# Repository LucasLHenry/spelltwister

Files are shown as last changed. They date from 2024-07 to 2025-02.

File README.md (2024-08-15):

# spelltwister
Spelltwister is a dual function generator with a large palette of modulation algorithms. It has three modes: ENV (slow, single-cycle), LFO (slow, free-running), and VCO (fast, free-running). Each side of the module is a waveformer, which generates a signal controlled by three knobs. The basic structure of this signal is that of an AD envelope, so the signal first rises to it's maximum value (in a variable time and curvature), then falls back to it's minimum value (in a variable time and curvature). 

The three knobs are Time, Shape, and Ratio. Time controls the overall time for one cycle of the waveform, so also functions as pitch in VCO mode. Ratio controls the ratio between the time spent on the first stage versus the second stage (so ratio set fully CCW would mean that all time is spent falling, which would form a downwards saw wave). Lastly, Shape controls the curvature of the rising and falling, from exponential to logarithmic. With Shape in it's center position, the slope is linear, but turning it below 12 o'clock makes the rising and falling more exponential, while turning it the other way makes it more logarithmic.

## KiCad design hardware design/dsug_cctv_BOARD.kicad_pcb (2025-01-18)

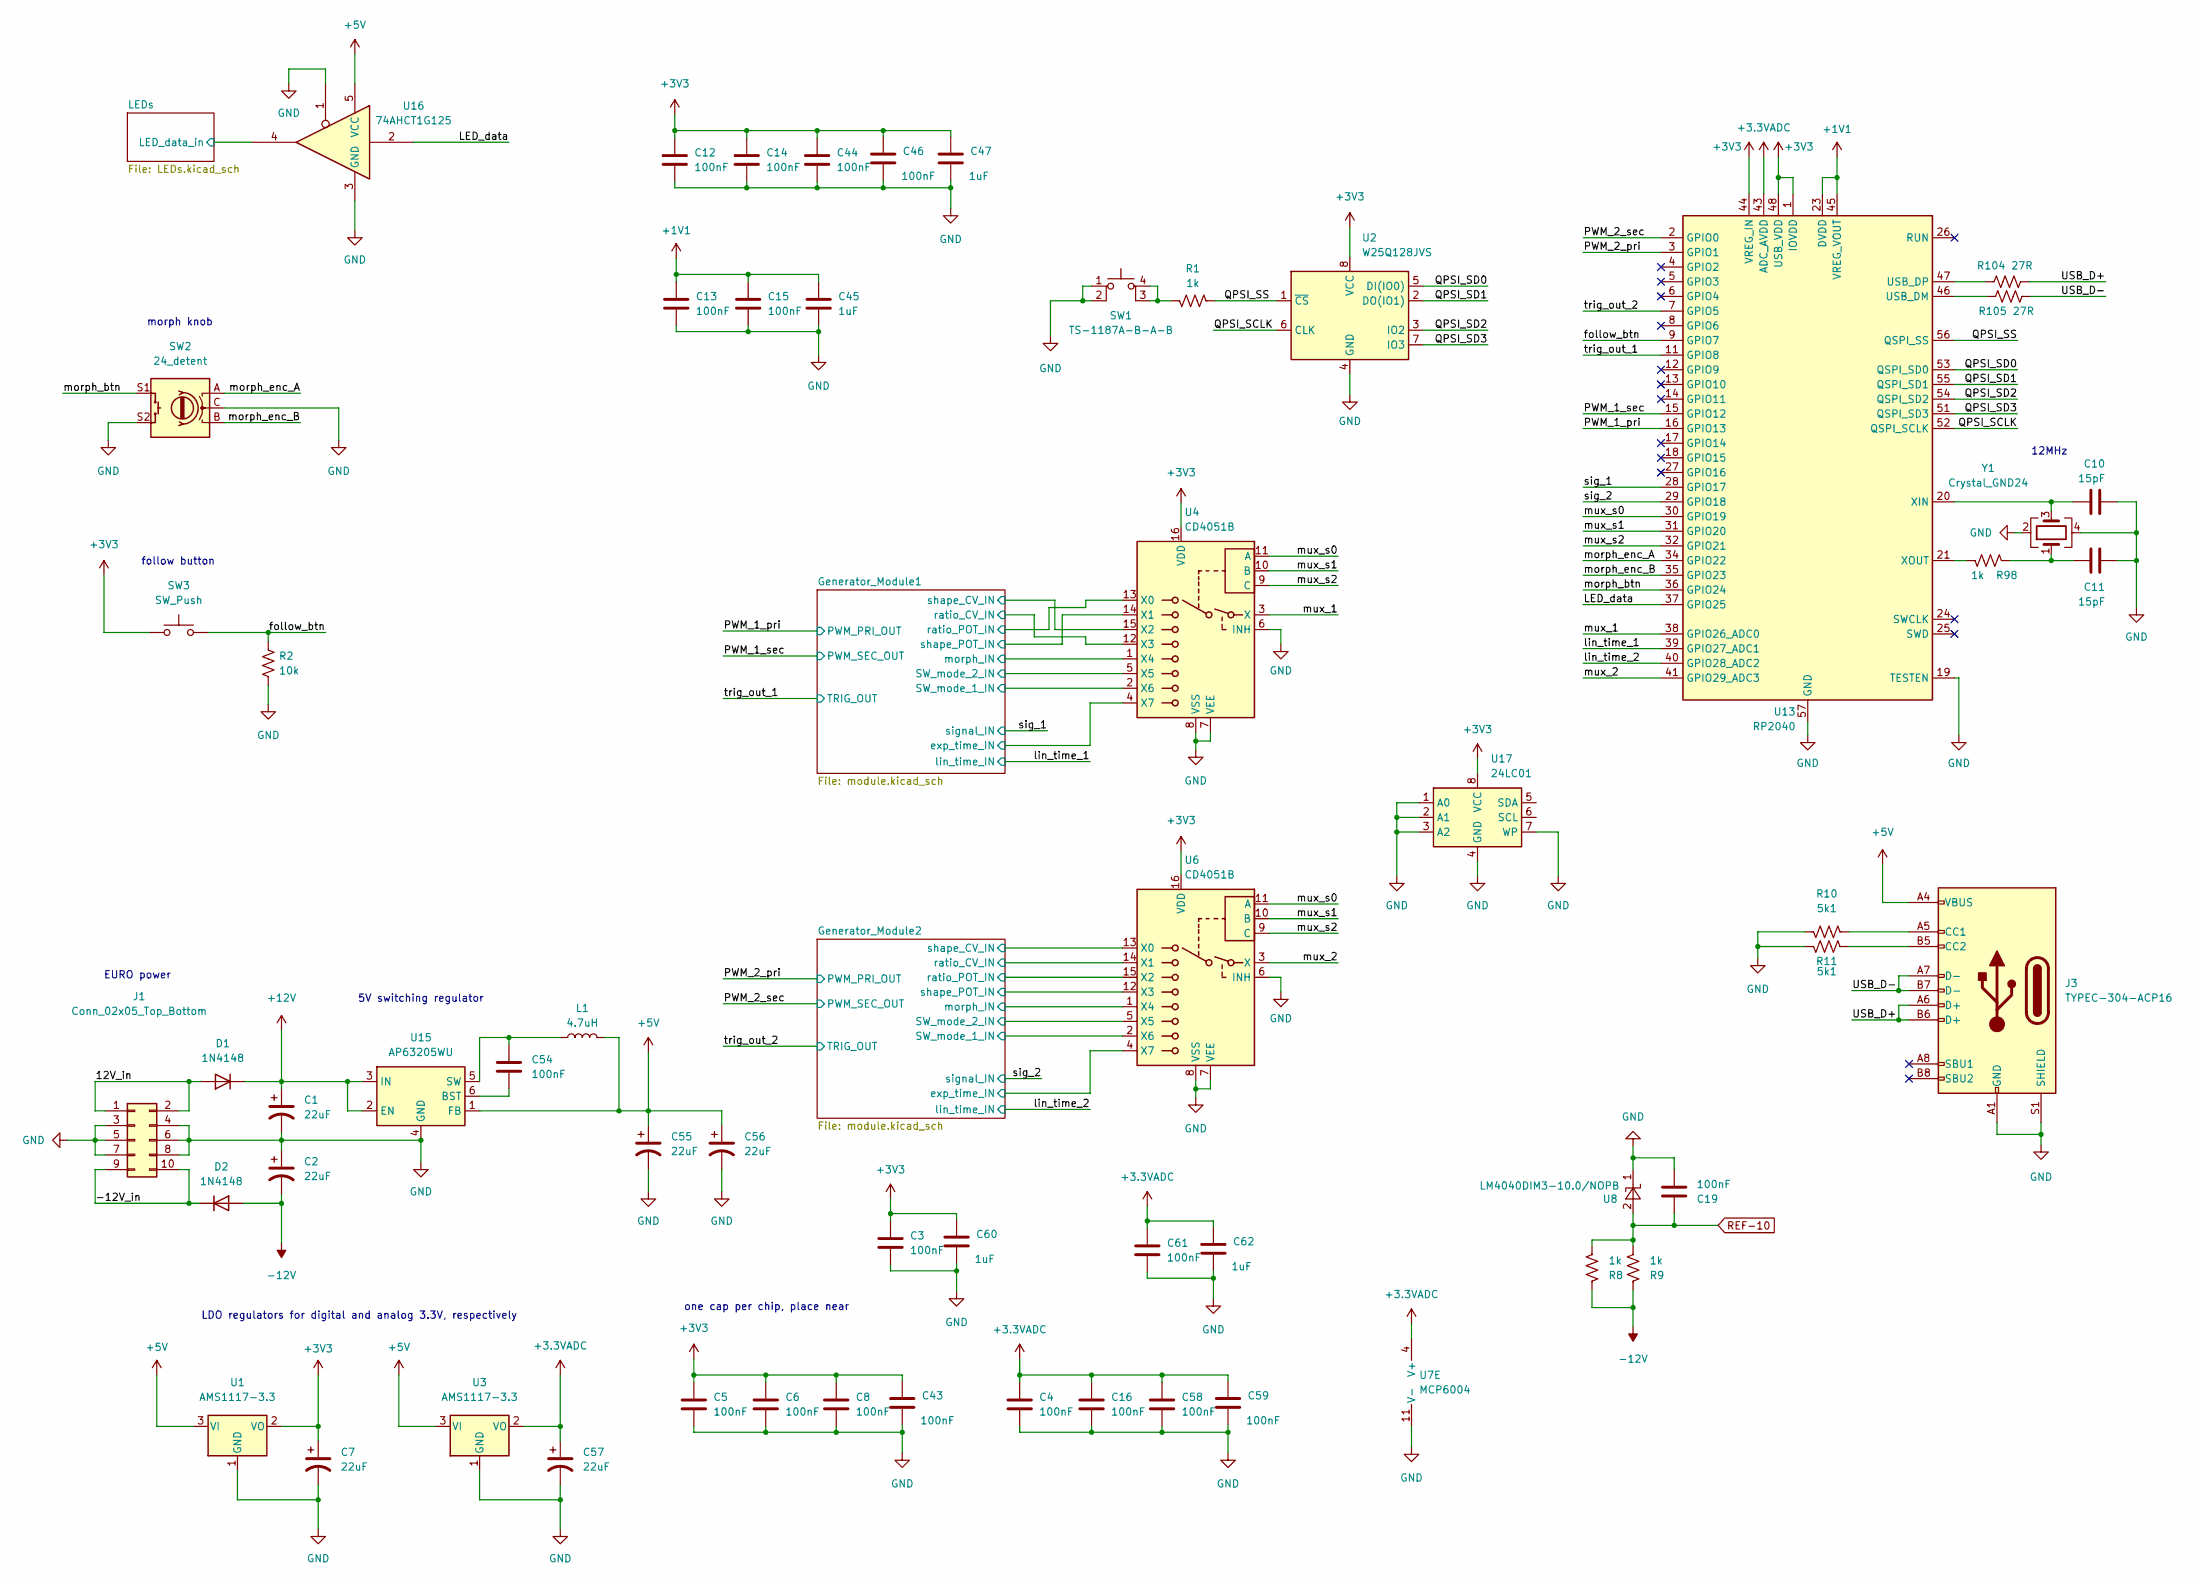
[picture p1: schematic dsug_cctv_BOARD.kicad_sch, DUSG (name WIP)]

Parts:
C1, C2, C7, C55, C56, C57: 22uF; CP_Radial_D5.0mm_P2.50mm
C3, C4, C5, C6, C8, C12, C13, C14, C15, C16, C19, C43, C44, C46, C54, C58, C59, C61: 100nF; C_0603_1608Metric
C10, C11: 15pF; C_0603_1608Metric
C45, C47, C60, C62: 1uF; C_0603_1608Metric
D1, D2: 1N4148; D_SOD-123
J1: Conn_02x05_Top_Bottom; PinHeader_2x05_P2.54mm_Vertical
J3: TYPEC-304-ACP16; USB_C_Receptacle_HRO_TYPE-C-31-M-12
L1: 4.7uH; L_TaiTech_HPC3010TF-4R7M
R1, R8, R9, R98: 1k; R_0603_1608Metric
R2: 10k; R_0603_1608Metric
R10, R11: 5k1; R_0603_1608Metric
R104, R105: 27R; R_0603_1608Metric
SW1: TS-1187A-B-A-B; push_switch_5.1x5.1
SW2: 24_detent; RotaryEncoder_Switch_Vertical_H20mm_20mm_knob
SW3: SW_Push; SW_PUSH_6mm
U1, U3: AMS1117-3.3; SOT-223-3_TabPin2
U2: W25Q128JVS; SOIC-8_5.23x5.23mm_P1.27mm
U4, U6: CD4051B; SOIC-16_3.9x9.9mm_P1.27mm
U7: MCP6004; SOIC-14_3.9x8.7mm_P1.27mm
U8: LM4040DIM3-10.0/NOPB; SOT-23
U13: RP2040; QFN-56-1EP_7x7mm_P0.4mm_EP3.2x3.2mm
U15: AP63205WU; TSOT-23-6
U16: 74AHCT1G125; SOT-353_SC-70-5
U17: 24LC01
Y1: Crystal_GND24; ABM8-272-T3_ABR

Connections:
+1V1: C13.1, C15.1, C45.1, U13.23 (DVDD), U13.45 (VREG_VOUT), U13.50 (DVDD)
+3.3VADC: C4.1, C16.1, C57.1, C58.1, C59.1, C61.1, C62.1, U3.2 (VO), U7.4 (V+), U13.43 (ADC_AVDD); also elsewhere on the board
+3V3: C3.1, C5.1, C6.1, C7.1, C8.1, C12.1, C14.1, C43.1, C44.1, C46.1, C47.1, C60.1, SW3.1, U1.2 (VO), U2.8 (VCC), U4.16 (VDD), U6.16 (VDD), U13.1 (IOVDD), U13.10 (IOVDD), U13.22 (IOVDD), U13.33 (IOVDD), U13.42 (IOVDD), U13.44 (VREG_IN), U13.48 (USB_VDD), U13.49 (IOVDD), U17.8 (VCC); also elsewhere on the board
+5V: C55.1, C56.1, J3.A4 (VBUS), J3.A9 (VBUS), J3.B4 (VBUS), J3.B9 (VBUS), L1.2, U1.3 (VI), U3.3 (VI), U15.1 (FB), U16.5 (VCC); also elsewhere on the board
+12V: C1.1, D1.1 (K), U15.2 (EN), U15.3 (IN); also elsewhere on the board
-12V: C2.2, D2.2 (A), R8.1, R9.1; also elsewhere on the board
/12V_in: D1.2 (A), J1.1, J1.2
/-12V_in: D2.1 (K), J1.9, J1.10
/Generator_Module1/SW_mode_1_IN: U4.2 (X6); also elsewhere on the board
/Generator_Module1/SW_mode_2_IN: U4.5 (X5); also elsewhere on the board
/Generator_Module1/exp_time_IN: U4.4 (X7); also elsewhere on the board
/Generator_Module1/morph_IN: U4.1 (X4); also elsewhere on the board
/Generator_Module1/ratio_CV_IN: U4.12 (X3); also elsewhere on the board
/Generator_Module1/ratio_pot: U4.13 (X0); also elsewhere on the board
/Generator_Module1/shape_CV_IN: U4.15 (X2); also elsewhere on the board
/Generator_Module1/shape_pot: U4.14 (X1); also elsewhere on the board
/Generator_Module2/SW_mode_1_IN: U6.2 (X6); also elsewhere on the board
/Generator_Module2/SW_mode_2_IN: U6.5 (X5); also elsewhere on the board
/Generator_Module2/exp_time_IN: U6.4 (X7); also elsewhere on the board
/Generator_Module2/morph_IN: U6.1 (X4), U7.14; also elsewhere on the board
/Generator_Module2/ratio_CV_IN: U6.14 (X1); also elsewhere on the board
/Generator_Module2/ratio_pot: U6.15 (X2); also elsewhere on the board
/Generator_Module2/shape_CV_IN: U6.13 (X0); also elsewhere on the board
/Generator_Module2/shape_pot: U6.12 (X3); also elsewhere on the board
/LED_data: U13.37 (GPIO25), U16.2
/LEDs/LED_data_in: U16.4; also elsewhere on the board
/PWM_1_pri: U13.16 (GPIO13); also elsewhere on the board
/PWM_1_sec: U13.15 (GPIO12); also elsewhere on the board
/PWM_2_pri: U13.3 (GPIO1); also elsewhere on the board
/PWM_2_sec: U13.2 (GPIO0); also elsewhere on the board
/QPSI_SCLK: U2.6 (CLK), U13.52 (QSPI_SCLK)
/QPSI_SD0: U2.5 (DI(IO0)), U13.53 (QSPI_SD0)
/QPSI_SD1: U2.2 (DO(IO1)), U13.55 (QSPI_SD1)
/QPSI_SD2: U2.3 (IO2), U13.54 (QSPI_SD2)
/QPSI_SD3: U2.7 (IO3), U13.51 (QSPI_SD3)
/QPSI_SS: R1.2, U2.1 (~CS), U13.56 (QSPI_SS)
/USB_D+: J3.A6 (D+), J3.B6 (D+), R104.2
/USB_D-: J3.A7 (D-), J3.B7 (D-), R105.2
/follow_btn: R2.1, SW3.2, U13.9 (GPIO7)
/lin_time_1: U13.39 (GPIO27_ADC1); also elsewhere on the board
/lin_time_2: U13.40 (GPIO28_ADC2); also elsewhere on the board
/morph_btn: SW2.S1, U13.36 (GPIO24)
/morph_enc_A: SW2.A, U13.34 (GPIO22)
/morph_enc_B: SW2.B, U13.35 (GPIO23)
/mux_1: U4.3 (X), U13.38 (GPIO26_ADC0)
/mux_2: U6.3 (X), U13.41 (GPIO29_ADC3)
/mux_s0: U4.11 (A), U6.11 (A), U13.30 (GPIO19)
/mux_s1: U4.10 (B), U6.10 (B), U13.31 (GPIO20)
/mux_s2: U4.9 (C), U6.9 (C), U13.32 (GPIO21)
/sig_1: U13.28 (GPIO17); also elsewhere on the board
/sig_2: U7.8, U13.29 (GPIO18); also elsewhere on the board
/trig_out_1: U13.11 (GPIO8); also elsewhere on the board
/trig_out_2: U13.7 (GPIO5); also elsewhere on the board
GND: C1.2, C2.1, C3.2, C4.2, C5.2, C6.2, C7.2, C8.2, C10.2, C11.2, C12.2, C13.2, C14.2, C15.2, C16.2, C19.2, C43.2, C44.2, C45.2, C46.2, C47.2, C55.2, C56.2, C57.2, C58.2, C59.2, C60.2, C61.2, C62.2, J1.3, J1.4, J1.5, J1.6, J1.7, J1.8, J3.A1 (GND), J3.A12 (GND), J3.B1 (GND), J3.B12 (GND), J3.S1 (SHIELD), R2.2, R10.2, R11.2, SW1.1, SW1.2, SW2.C, SW2.S2, U1.1 (GND), U2.4 (GND), U3.1 (GND), U4.6 (INH), U4.7 (VEE), U4.8 (VSS), U6.6 (INH), U6.7 (VEE), U6.8 (VSS), U7.10 (+), U7.11 (V-), U7.12 (+), U8.1 (K), U13.19 (TESTEN), U13.57 (GND), U15.4 (GND), U16.1, U16.3 (GND), U17.1 (A0), U17.2 (A1), U17.3 (A2), U17.4 (GND), U17.7 (WP), Y1.2, Y1.4; also elsewhere on the board
unnamed: C11.1, R98.1, Y1.1
unnamed: J3.A5 (CC1), R10.1
unnamed: J3.B5 (CC2), R11.1
unnamed: R1.1, SW1.3 (K), SW1.4 (A)
unnamed 140: U7.9 (-); also elsewhere on the board
unnamed 141: U7.13 (-); also elsewhere on the board
unnamed: R105.1, U13.46 (USB_DM)
unnamed: R104.1, U13.47 (USB_DP)
unnamed: C10.1, U13.20 (XIN), Y1.3
unnamed: R98.2, U13.21 (XOUT)
unnamed: C54.2, U15.6 (BST)
unnamed: C54.1, L1.1, U15.5 (SW)
REF-10: C19.1, R8.2, R9.2, U8.2 (A); also elsewhere on the board

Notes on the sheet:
one cap per chip, place near
5V switching regulator
LDO regulators for digital and analog 3.3V, respectively
EURO power
morph knob
12MHz
follow button

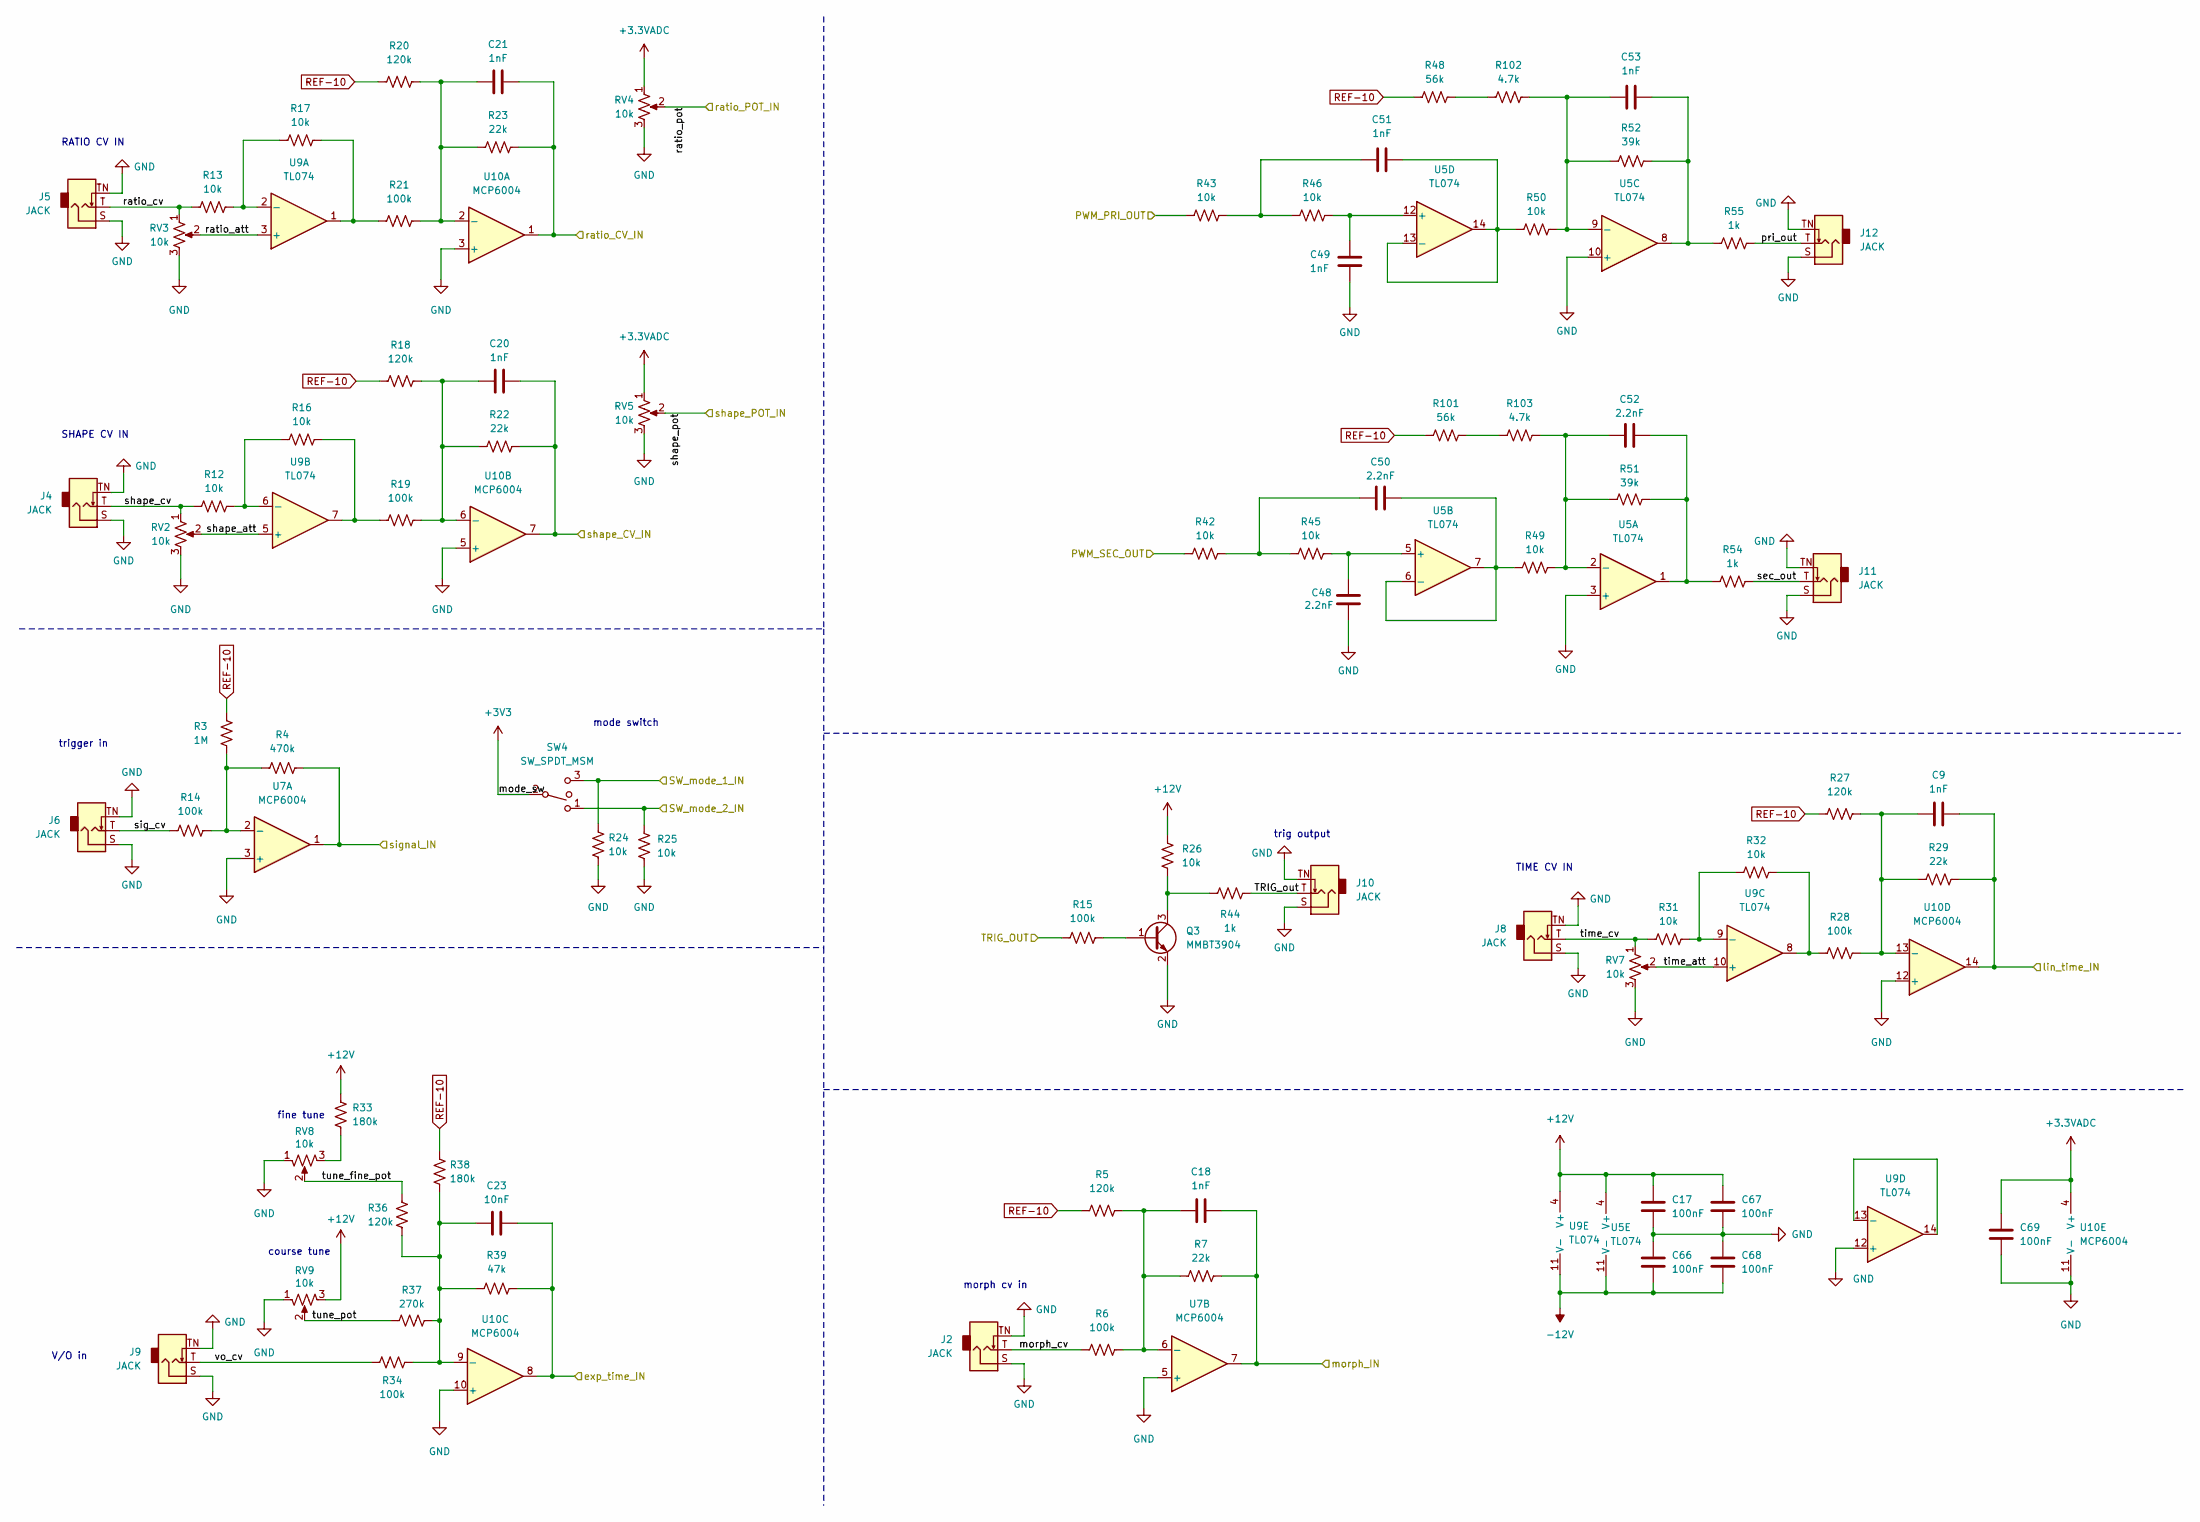
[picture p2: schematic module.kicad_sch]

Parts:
C9, C18, C20, C21, C49, C51, C53: 1nF; C_0603_1608Metric
C17, C66, C67, C68, C69: 100nF; C_0603_1608Metric
C23: 10nF; C_0603_1608Metric
C48, C50, C52: 2.2nF; C_0603_1608Metric
J2, J4, J5, J6, J8, J9, J10, J11, J12: JACK; AudioJack_3.5mm_with_drawing
Q3: MMBT3904; SOT-23
R3: 1M; R_0603_1608Metric
R4: 470k; R_0603_1608Metric
R5, R18, R20, R27, R36: 120k; R_0603_1608Metric
R6, R14, R15, R19, R21, R28, R34: 100k; R_0603_1608Metric
R7, R22, R23, R29: 22k; R_0603_1608Metric
R12, R13, R16, R17, R24, R25, R26, R31, R32, R42, R43, R45, R46, R49, R50: 10k; R_0603_1608Metric
R33, R38: 180k; R_0603_1608Metric
R37: 270k; R_0603_1608Metric
R39: 47k; R_0603_1608Metric
R44, R54, R55: 1k; R_0603_1608Metric
R48, R101: 56k; R_0603_1608Metric
R51, R52: 39k; R_0603_1608Metric
R102, R103: 4.7k; R_0603_1608Metric
RV2, RV3, RV7, RV8: 10k; Potentiometer_RV09_talltrimmer
RV4, RV5, RV9: 10k; Potentiometer_RV09_6mm_knob
SW4: SW_SPDT_MSM; SPDT_P2.54mm_Vertical
U5, U9: TL074; SOIC-14_3.9x8.7mm_P1.27mm
U7, U10: MCP6004; SOIC-14_3.9x8.7mm_P1.27mm

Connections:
+3.3VADC: C69.1, RV4.1, RV5.1, U10.4 (V+); also elsewhere on the board
+3V3: SW4.2; also elsewhere on the board
+12V: C17.1, C67.1, R26.1, R33.1, RV9.3, U5.4 (V+), U9.4 (V+); also elsewhere on the board
-12V: C66.2, C68.2, U5.11 (V-), U9.11 (V-); also elsewhere on the board
/Generator_Module1/SW_mode_1_IN: R24.1, SW4.3; also elsewhere on the board
/Generator_Module1/SW_mode_2_IN: R25.1, SW4.1; also elsewhere on the board
/Generator_Module1/TRIG_out: J10.T, R44.1
/Generator_Module1/exp_time_IN: C23.2, R39.2, U10.8; also elsewhere on the board
/Generator_Module1/morph_IN: C18.2, R7.2, U7.7; also elsewhere on the board
/Generator_Module1/morph_cv: J2.T, R6.1
/Generator_Module1/pri_out: J12.T, R55.2
/Generator_Module1/ratio_CV_IN: C21.2, R23.2, U10.1; also elsewhere on the board
/Generator_Module1/ratio_att: RV3.2, U9.3 (+)
/Generator_Module1/ratio_cv: J5.T, R13.1, RV3.1
/Generator_Module1/ratio_pot: RV4.2; also elsewhere on the board
/Generator_Module1/sec_out: J11.T, R54.2
/Generator_Module1/shape_CV_IN: C20.2, R22.2, U10.7; also elsewhere on the board
/Generator_Module1/shape_att: RV2.2, U9.5 (+)
/Generator_Module1/shape_cv: J4.T, R12.1, RV2.1
/Generator_Module1/shape_pot: RV5.2; also elsewhere on the board
/Generator_Module1/sig_cv: J6.T, R14.1
/Generator_Module1/time_att: RV7.2, U9.10 (+)
/Generator_Module1/time_cv: J8.T, R31.1, RV7.1
/Generator_Module1/tune_fine_pot: R36.1, RV8.2
/Generator_Module1/tune_pot: R37.1, RV9.2
/Generator_Module1/vo_cv: J9.T, R34.1
/Generator_Module2/morph_IN: U7.14; also elsewhere on the board
/PWM_1_pri: R43.1; also elsewhere on the board
/PWM_1_sec: R42.1; also elsewhere on the board
/lin_time_1: C9.2, R29.2, U10.14; also elsewhere on the board
/sig_1: R4.2, U7.1; also elsewhere on the board
/sig_2: U7.8; also elsewhere on the board
/trig_out_1: R15.1; also elsewhere on the board
GND: C17.2, C48.1, C49.2, C66.1, C67.2, C68.1, C69.2, J2.S, J2.TN, J4.S, J4.TN, J5.S, J5.TN, J6.S, J6.TN, J8.S, J8.TN, J9.S, J9.TN, J10.S, J10.TN, J11.S, J11.TN, J12.S, J12.TN, Q3.2 (E), R24.2, R25.2, RV2.3, RV3.3, RV4.3, RV5.3, RV7.3, RV8.1, RV9.1, U5.3 (+), U5.10 (+), U7.3 (+), U7.5 (+), U7.10 (+), U7.12 (+), U9.12 (+), U10.3 (+), U10.5 (+), U10.10 (+), U10.11 (V-), U10.12 (+); also elsewhere on the board
unnamed: C50.1, R42.2, R45.1
unnamed: C51.1, R43.2, R46.1
unnamed: C52.2, R51.2, R54.1, U5.1
unnamed: C53.2, R52.2, R55.1, U5.8
unnamed: Q3.1 (B), R15.2
unnamed: Q3.3 (C), R26.2, R44.2
unnamed: R16.2, R19.1, U9.7
unnamed: R17.2, R21.1, U9.1
unnamed: R28.1, R32.2, U9.8
unnamed: R33.2, RV8.3
unnamed: R101.2, R103.1
unnamed: R48.2, R102.1
unnamed: C52.1, R49.2, R51.1, R103.2, U5.2 (-)
unnamed: C48.2, R45.2, U5.5 (+)
unnamed: C50.2, R49.1, U5.6 (-), U5.7
unnamed: C53.1, R50.2, R52.1, R102.2, U5.9 (-)
unnamed: C49.1, R46.2, U5.12 (+)
unnamed: C51.2, R50.1, U5.13 (-), U5.14
unnamed: R3.1, R4.1, R14.2, U7.2 (-)
unnamed: C18.1, R5.2, R6.2, R7.1, U7.6 (-)
unnamed 140: U7.9 (-); also elsewhere on the board
unnamed 141: U7.13 (-); also elsewhere on the board
unnamed: R13.2, R17.1, U9.2 (-)
unnamed: R12.2, R16.1, U9.6 (-)
unnamed: R31.2, R32.1, U9.9 (-)
unnamed: U9.13 (-), U9.14
unnamed: C21.1, R20.2, R21.2, R23.1, U10.2 (-)
unnamed: C20.1, R18.2, R19.2, R22.1, U10.6 (-)
unnamed: C23.1, R34.2, R36.2, R37.2, R38.1, R39.1, U10.9 (-)
unnamed: C9.1, R27.2, R28.2, R29.1, U10.13 (-)
REF-10: R3.2, R5.1, R18.1, R20.1, R27.1, R38.2, R48.1, R101.1; also elsewhere on the board

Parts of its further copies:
C22: 10nF; C_0603_1608Metric
C28, C29, C30, C32, C34, C36, C41: 1nF; C_0603_1608Metric
C31, C33, C35: 2.2nF; C_0603_1608Metric
C37, C38, C39, C40, C42: 100nF; C_0603_1608Metric
J7, J13, J14, J15, J16, J17, J18, J19, J20: JACK; AudioJack_3.5mm_with_drawing
Q4: MMBT3904; SOT-23
R30: 1M; R_0603_1608Metric
R35, R59, R61, R63, R72, R74, R96: 100k; R_0603_1608Metric
R40, R41, R56, R57, R70, R71, R75, R77, R78, R80, R81, R86, R87, R91, R94: 10k; R_0603_1608Metric
R53: 470k; R_0603_1608Metric
R58, R66: 180k; R_0603_1608Metric
R60, R62, R64, R73, R95: 120k; R_0603_1608Metric
R65: 270k; R_0603_1608Metric
R67: 47k; R_0603_1608Metric
R68, R69, R76, R97: 22k; R_0603_1608Metric
R79, R92, R93: 1k; R_0603_1608Metric
R82, R83: 56k; R_0603_1608Metric
R84, R85: 4.7k; R_0603_1608Metric
R89, R90: 39k; R_0603_1608Metric
RV1, RV6, RV10, RV14: 10k; Potentiometer_RV09_talltrimmer
RV11, RV12, RV13: 10k; Potentiometer_RV09_6mm_knob
SW5: SW_SPDT_MSM; SPDT_P2.54mm_Vertical
U11: MCP6004; SOIC-14_3.9x8.7mm_P1.27mm
U12, U14: TL074; SOIC-14_3.9x8.7mm_P1.27mm

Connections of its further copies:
+3.3VADC: C42.1, RV12.1, RV13.1, U11.4 (V+); also elsewhere on the board
+3V3: SW5.2; also elsewhere on the board
+12V: C37.1, C39.1, R58.1, R75.1, RV11.3, U12.4 (V+), U14.4 (V+); also elsewhere on the board
-12V: C38.2, C40.2, U12.11 (V-), U14.11 (V-); also elsewhere on the board
/Generator_Module2/SW_mode_1_IN: R70.1, SW5.3; also elsewhere on the board
/Generator_Module2/SW_mode_2_IN: R71.1, SW5.1; also elsewhere on the board
/Generator_Module2/TRIG_out: J17.T, R79.1
/Generator_Module2/exp_time_IN: C22.2, R67.2, U11.8; also elsewhere on the board
/Generator_Module2/morph_IN: C30.2, R76.2; also elsewhere on the board
/Generator_Module2/morph_cv: J16.T, R74.1
/Generator_Module2/pri_out: J20.T, R93.2
/Generator_Module2/ratio_CV_IN: C28.2, R68.2, U11.1; also elsewhere on the board
/Generator_Module2/ratio_att: RV1.2, U12.3 (+)
/Generator_Module2/ratio_cv: J7.T, R40.1, RV1.1
/Generator_Module2/ratio_pot: RV13.2; also elsewhere on the board
/Generator_Module2/sec_out: J19.T, R92.2
/Generator_Module2/shape_CV_IN: C29.2, R69.2, U11.7; also elsewhere on the board
/Generator_Module2/shape_att: RV6.2, U12.5 (+)
/Generator_Module2/shape_cv: J13.T, R41.1, RV6.1
/Generator_Module2/shape_pot: RV12.2; also elsewhere on the board
/Generator_Module2/sig_cv: J14.T, R35.1
/Generator_Module2/time_att: RV14.2, U12.10 (+)
/Generator_Module2/time_cv: J18.T, R91.1, RV14.1
/Generator_Module2/tune_fine_pot: R64.1, RV10.2
/Generator_Module2/tune_pot: R65.1, RV11.2
/Generator_Module2/vo_cv: J15.T, R59.1
/PWM_2_pri: R78.1; also elsewhere on the board
/PWM_2_sec: R77.1; also elsewhere on the board
/lin_time_2: C41.2, R97.2, U11.14; also elsewhere on the board
/sig_2: R53.2; also elsewhere on the board
/trig_out_2: R72.1; also elsewhere on the board
GND: C31.1, C32.2, C37.2, C38.1, C39.2, C40.1, C42.2, J7.S, J7.TN, J13.S, J13.TN, J14.S, J14.TN, J15.S, J15.TN, J16.S, J16.TN, J17.S, J17.TN, J18.S, J18.TN, J19.S, J19.TN, J20.S, J20.TN, Q4.2 (E), R70.2, R71.2, RV1.3, RV6.3, RV10.1, RV11.1, RV12.3, RV13.3, RV14.3, U11.3 (+), U11.5 (+), U11.10 (+), U11.11 (V-), U11.12 (+), U12.12 (+), U14.5 (+), U14.12 (+); also elsewhere on the board
unnamed: C33.1, R77.2, R80.1
unnamed: C34.1, R78.2, R81.1
unnamed: C35.2, R89.2, R92.1, U14.14
unnamed: C36.2, R90.2, R93.1, U14.7
unnamed: Q4.1 (B), R72.2
unnamed: Q4.3 (C), R75.2, R79.2
unnamed: R56.2, R61.1, U12.1
unnamed: R57.2, R63.1, U12.7
unnamed: R58.2, RV10.3
unnamed: R82.2, R84.1
unnamed: R83.2, R85.1
unnamed: R94.2, R96.1, U12.8
unnamed 140: R30.1, R35.2, R53.1; also elsewhere on the board
unnamed 141: C30.1, R73.2, R74.2, R76.1; also elsewhere on the board
unnamed: C28.1, R60.2, R61.2, R68.1, U11.2 (-)
unnamed: C29.1, R62.2, R63.2, R69.1, U11.6 (-)
unnamed: C22.1, R59.2, R64.2, R65.2, R66.1, R67.1, U11.9 (-)
unnamed: C41.1, R95.2, R96.2, R97.1, U11.13 (-)
unnamed: R40.2, R56.1, U12.2 (-)
unnamed: R41.2, R57.1, U12.6 (-)
unnamed: R91.2, R94.1, U12.9 (-)
unnamed: U12.13 (-), U12.14
unnamed: C32.1, R81.2, U14.3 (+)
unnamed: C34.2, R87.1, U14.1, U14.2 (-)
unnamed: C36.1, R84.2, R87.2, R90.1, U14.6 (-)
unnamed: C31.2, R80.2, U14.10 (+)
unnamed: C33.2, R86.1, U14.8, U14.9 (-)
unnamed: C35.1, R85.2, R86.2, R89.1, U14.13 (-)
REF-10: R30.2, R60.1, R62.1, R66.2, R73.1, R82.1, R83.1, R95.1; also elsewhere on the board

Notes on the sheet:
course tune
morph cv in
trig output
SHAPE CV IN
V/O in
fine tune
RATIO CV IN
mode switch
TIME CV IN
trigger in

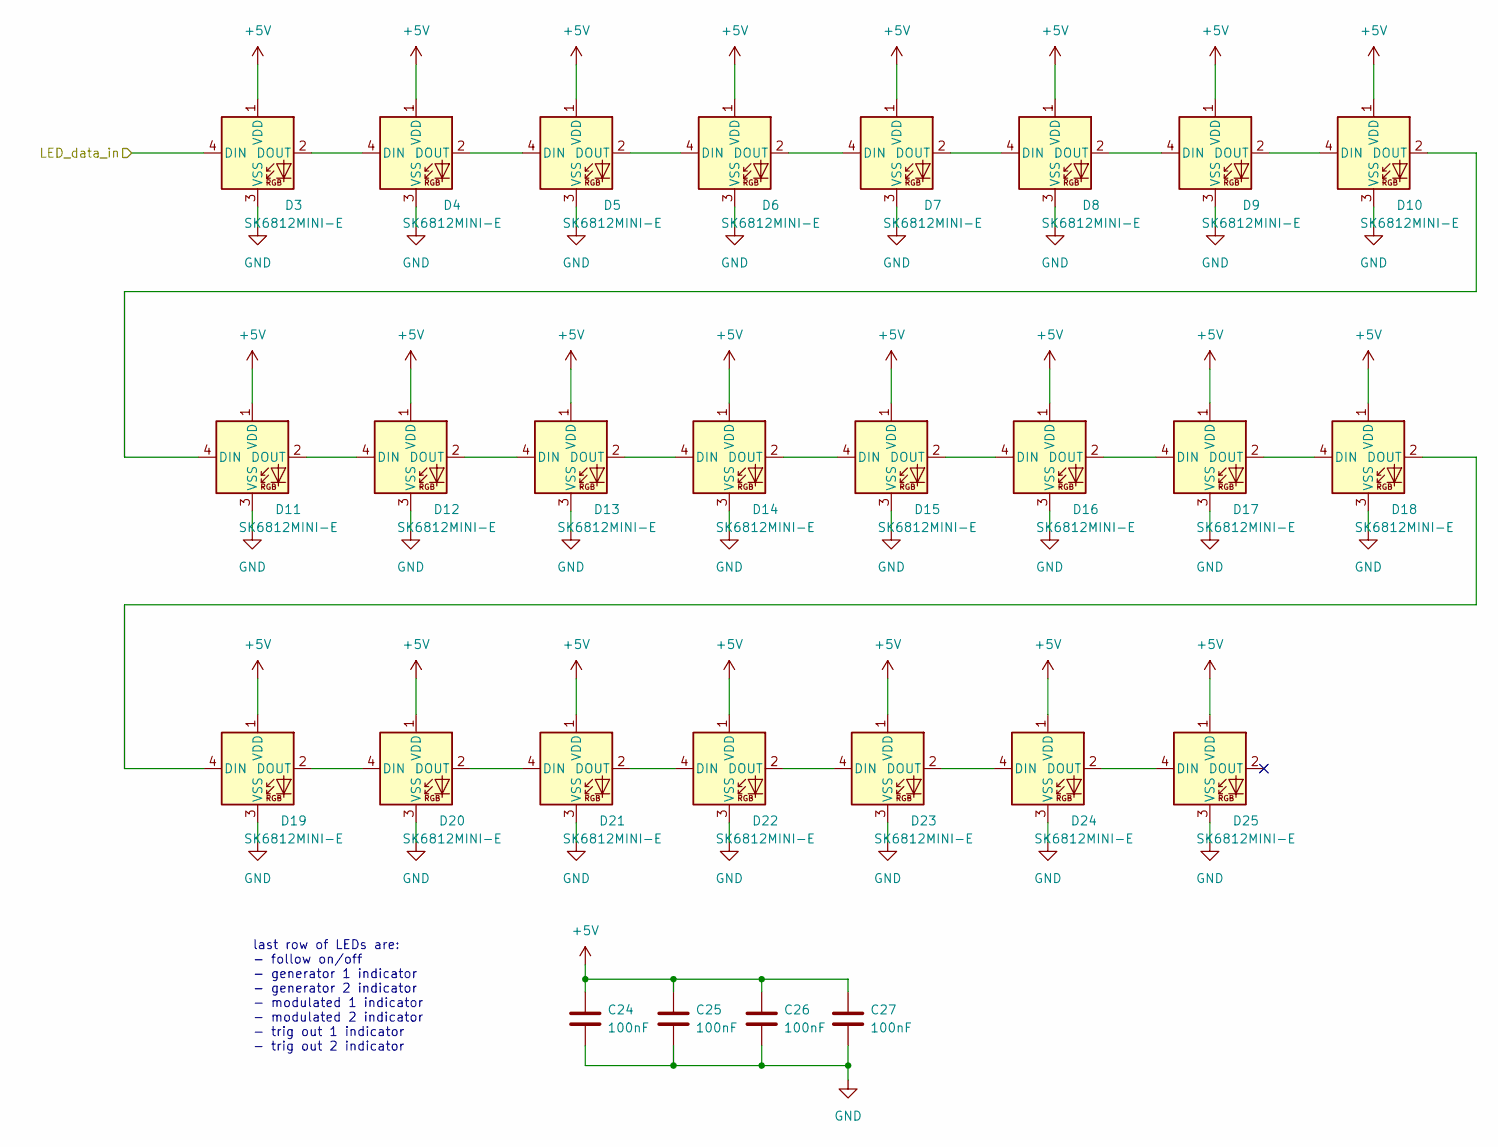
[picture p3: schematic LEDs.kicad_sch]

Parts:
C24, C25, C26, C27: 100nF; C_0603_1608Metric
D3, D4, D5, D6, D7, D8, D9, D10, D11, D12, D13, D14, D15, D16, D17, D18, D19, D20, D21, D22, D23, D24, D25: SK6812MINI-E; SK6812MINIE

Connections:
+5V: C24.1, C25.1, C26.1, C27.1, D3.1 (VDD), D4.1 (VDD), D5.1 (VDD), D6.1 (VDD), D7.1 (VDD), D8.1 (VDD), D9.1 (VDD), D10.1 (VDD), D11.1 (VDD), D12.1 (VDD), D13.1 (VDD), D14.1 (VDD), D15.1 (VDD), D16.1 (VDD), D17.1 (VDD), D18.1 (VDD), D19.1 (VDD), D20.1 (VDD), D21.1 (VDD), D22.1 (VDD), D23.1 (VDD), D24.1 (VDD), D25.1 (VDD); also elsewhere on the board
/LEDs/LED_data_in: D3.4 (DIN); also elsewhere on the board
GND: C24.2, C25.2, C26.2, C27.2, D3.3 (VSS), D4.3 (VSS), D5.3 (VSS), D6.3 (VSS), D7.3 (VSS), D8.3 (VSS), D9.3 (VSS), D10.3 (VSS), D11.3 (VSS), D12.3 (VSS), D13.3 (VSS), D14.3 (VSS), D15.3 (VSS), D16.3 (VSS), D17.3 (VSS), D18.3 (VSS), D19.3 (VSS), D20.3 (VSS), D21.3 (VSS), D22.3 (VSS), D23.3 (VSS), D24.3 (VSS), D25.3 (VSS); also elsewhere on the board
unnamed: D3.2 (DOUT), D4.4 (DIN)
unnamed: D4.2 (DOUT), D5.4 (DIN)
unnamed: D5.2 (DOUT), D6.4 (DIN)
unnamed: D6.2 (DOUT), D7.4 (DIN)
unnamed: D7.2 (DOUT), D8.4 (DIN)
unnamed: D8.2 (DOUT), D9.4 (DIN)
unnamed: D9.2 (DOUT), D10.4 (DIN)
unnamed: D10.2 (DOUT), D11.4 (DIN)
unnamed: D11.2 (DOUT), D12.4 (DIN)
unnamed: D12.2 (DOUT), D13.4 (DIN)
unnamed: D13.2 (DOUT), D14.4 (DIN)
unnamed: D14.2 (DOUT), D15.4 (DIN)
unnamed: D15.2 (DOUT), D16.4 (DIN)
unnamed: D16.2 (DOUT), D17.4 (DIN)
unnamed: D17.2 (DOUT), D18.4 (DIN)
unnamed: D18.2 (DOUT), D19.4 (DIN)
unnamed: D19.2 (DOUT), D20.4 (DIN)
unnamed: D20.2 (DOUT), D21.4 (DIN)
unnamed: D21.2 (DOUT), D22.4 (DIN)
unnamed: D22.2 (DOUT), D23.4 (DIN)
unnamed: D23.2 (DOUT), D24.4 (DIN)
unnamed: D24.2 (DOUT), D25.4 (DIN)

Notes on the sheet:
last row of LEDs are: - follow on/off - generator 1 indicator - generator 2 indicator - modulated 1 indicator - modulated 2 indicator - trig out 1 indicator - trig out 2 indicator

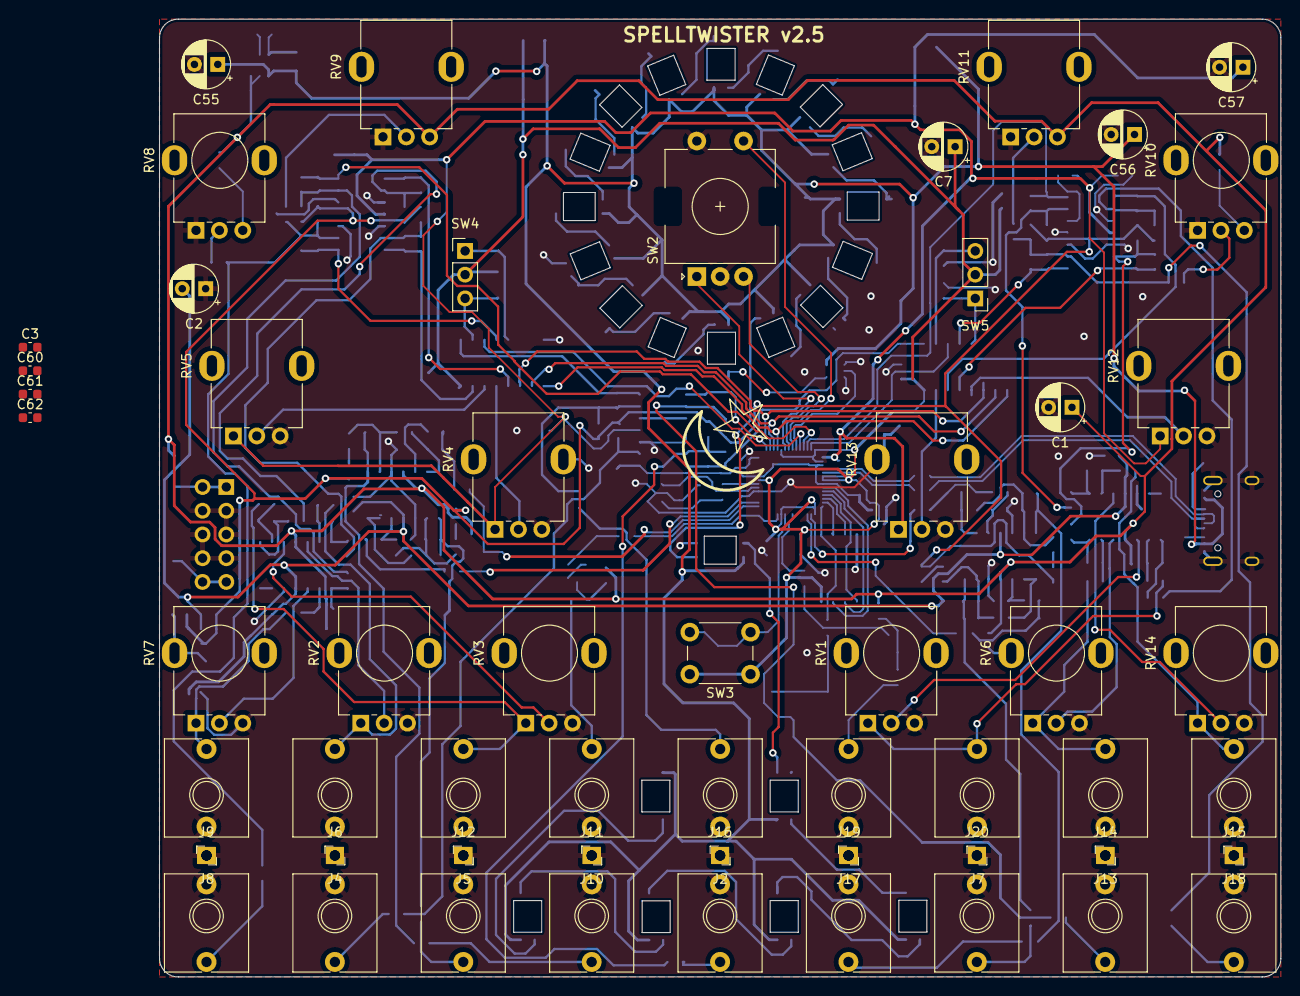
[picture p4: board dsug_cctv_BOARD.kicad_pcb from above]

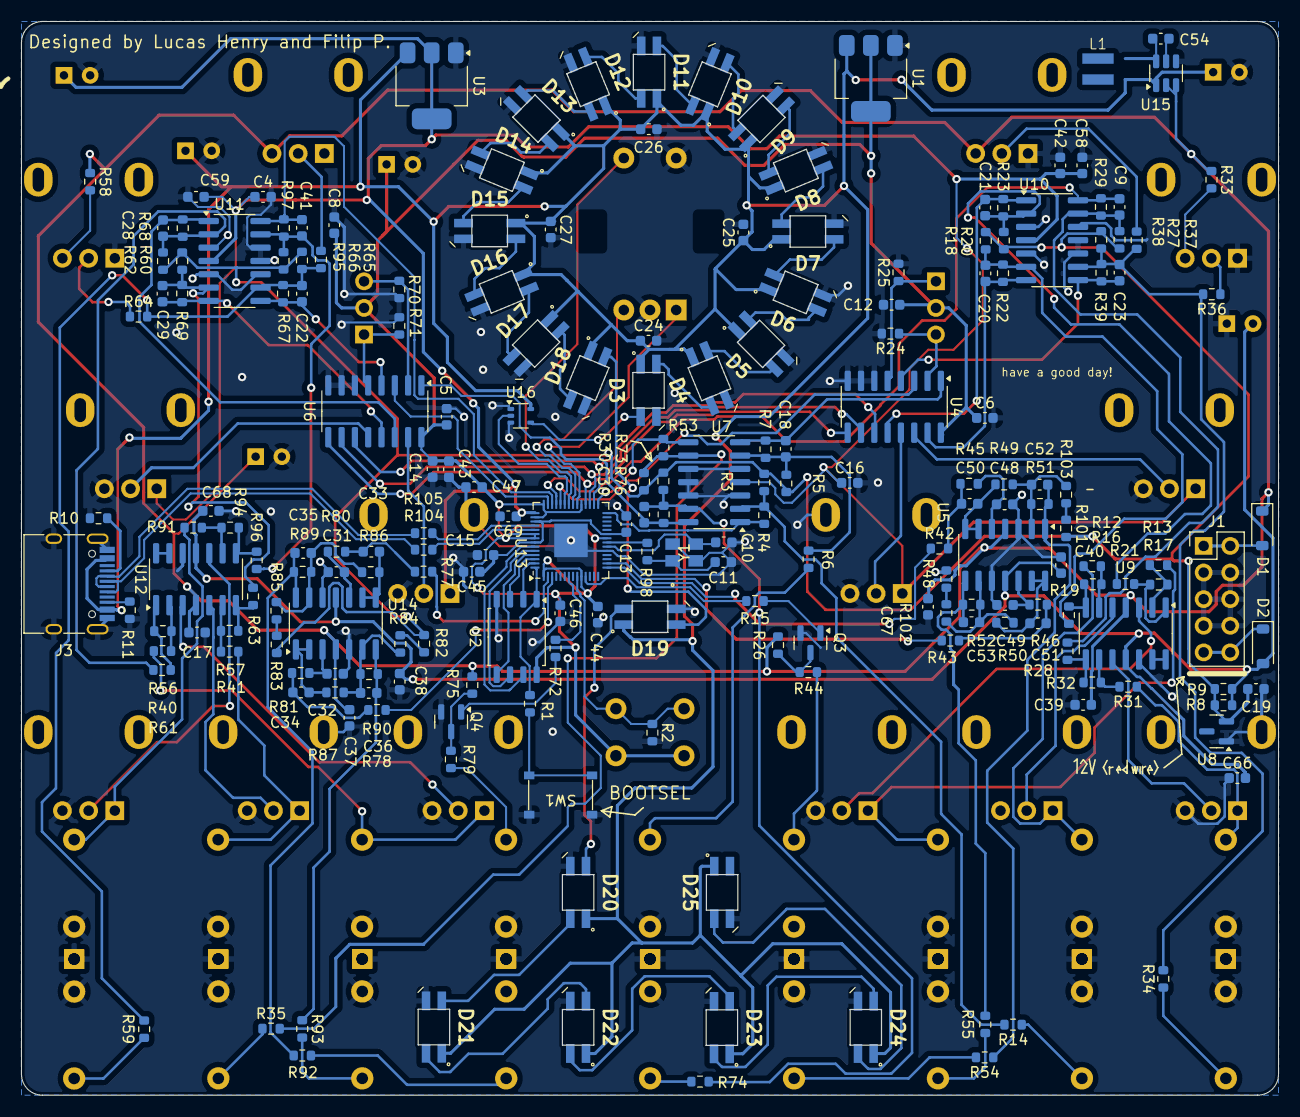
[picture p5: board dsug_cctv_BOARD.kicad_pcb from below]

Board: 2 copper layers, 120.0 x 102.5 mm, 251 parts (205 on the bottom side), 171 nets.

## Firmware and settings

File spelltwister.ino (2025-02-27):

/*
Developed by Lucas Henry, May 2024

The main entry point file for the firmware, showing high-level logic.
*/

#include <Arduino.h>
#include <Adafruit_NeoPXL8.h>
#include <hardware/pwm.h>

#include "src/classes/Waveformer/waveformer.h"
#include "src/classes/LedRing/led_ring.h"
#include "src/classes/Modulator/modulator.h"
#include "src/classes/NVMWrapper/nvm_wrapper.h"
#include "src/hardware/pins.h"
#include "src/hardware/misc_functions.h"
#include "src/hardware/calibration.h"
#include "src/constants.hpp"
#include "src/wave_algos/generator.h"
#include "src/wave_algos/mod_algorithms.h"
#include "src/tables/colours.h"


// --- SELECTED RING ALGORITHMS ---
// on the front panel, runs clockwise starting at the bottom
algo_f_ptr algo_arr[16] = {
    sine_pm,
    maximum,
    phase_offset,
    double_freq,
    invert,
    half_freq,
    sum,
    amplitude_mod,
    harmonic_fm,
    frequency_mod,
    crosscrush,
    sample_and_hold,
    rungle,
    exclusive_or,
    binary_and,
    binary_or   
};

// --- GLOBAL VARIABLES ---
int8_t led_pins[8] = LED_DATA;  // pin setup for led strip
Adafruit_NeoPXL8 leds(NUM_LEDS, led_pins, NEO_GRB);  // led strip controller
LedRing ring(ALGO_ENC_1, ALGO_ENC_2, ALGO_BTN);  // algorithm ring controller
LedRing* _LEDRING = &ring; // used for internal ISR stuff
OneButton follow_btn(FLW_BTN, false, false);  // follow button

Waveformer a(true,  MUX_A, LIN_TIME_A);  // left side waveform generator
Waveformer b(false, MUX_B, LIN_TIME_B);  // right side waveform generator
Modulator mod_a(a, b, ring, algo_arr);  // left side waveform modulator
Modulator mod_b(b, a, ring, algo_arr);  // right side waveform modulator

NVMWrapper nvm;  // interface for loading/storing config data

bool save_mod_pos_flag;  // flag raised when user triggers encoder position save
uint16_t a_pwm_slice, b_pwm_slice;  // hardware PWM slices allocated to A and B
bool calibrating = false;  // indicates code is in a calibration state
repeating_timer_t pwm_timer;

// --- FORWARD DECLARATIONS ---
void encoder_long_press_ISR();
void follow_ISR();
bool pwm_timer_ISR(repeating_timer_t* rt);
void a_sync_ISR();
void b_sync_ISR();
void write_other_leds();

// --- CORE 0 SETUP/LOOP ---
void setup() {
    analogReadResolution(BITS_ADC);
    Serial.begin(9600);

    // initialize objects
    a.init(&b);
    b.init(&a);
    nvm = NVMWrapper();
    a.configs = nvm.get_config_data(true);
    b.configs = nvm.get_config_data(false);
    ring.reversed = nvm.get_encoder_direction();
    if (nvm.get_follow()) {
        b.toggle_follow_mode();
    }
    leds.begin();
    leds.setBrightness(0x70);

    // calibration mode
    if (digitalRead(FLW_BTN) == HIGH) {
        calibrating = true;
        run_calibration(a, b, leds, ring, nvm);
        calibrating = false;
    }

    ring.btn.attachLongPressStart(encoder_long_press_ISR);
    ring.btn.setPressMs(3000);
    ring.begin(nvm.get_mod_pos(true), nvm.get_mod_pos(false));

    follow_btn.attachClick(follow_ISR);
}

void loop() {
    // save state if triggered
    if (save_mod_pos_flag) {
        blink(leds, mix_colour, 50, 300);
        nvm.set_mod_pos(true, ring.a_idx_wo_cv);
        nvm.set_mod_pos(false, ring.b_idx_wo_cv);
        nvm.set_follow(b.get_follow());
        nvm.save_mod_pos();
        pwm_set_enabled(a_pwm_slice, true);
        pwm_set_enabled(b_pwm_slice, true);
        save_mod_pos_flag = false;
    }

    // read inputs
    a.read();
    b.read();
    follow_btn.tick();
    ring.update(a.mod_idx, b.mod_idx);
    
    ring.write_leds(leds);
    write_other_leds();
    leds.show();
}


// --- CORE 1 SETUP/LOOP ---
void setup1() {
    // setup outputs
    constexpr uint16_t max_val = (1 << BIT_DEPTH) - 1;
    a_pwm_slice = setup_pwm_pins(PRI_OUT_A, SEC_OUT_A, max_val);
    b_pwm_slice = setup_pwm_pins(PRI_OUT_B, SEC_OUT_B, max_val);
    pinMode(TRIG_OUT_A, OUTPUT);
    pinMode(TRIG_OUT_B, OUTPUT);

    // timer setup
    int64_t timer_period_us = - (1000 / PWM_FREQ_kHz);  // negative means include execution time in period
    alarm_pool_t* pool = alarm_pool_create(0, 1);
    alarm_pool_add_repeating_timer_us(pool, timer_period_us, pwm_timer_ISR, NULL, &pwm_timer);

    // interrupt setup
    attachInterrupt(digitalPinToInterrupt(SIG_IN_A), a_sync_ISR, FALLING);
    attachInterrupt(digitalPinToInterrupt(SIG_IN_B), b_sync_ISR, FALLING);
}

void loop1() {}


// --- OTHER FUNCTIONS ---

bool pwm_timer_ISR(repeating_timer_t* rt) {
    if (calibrating) return true;
    // increment phasors etc.
    a.update();
    b.update();

    // create new outputs
    a.generate();
    b.generate();
    mod_a.generate();
    mod_b.generate();

    // push new values to outputs
    // subtract max_x to account for filter signal inversion
    pwm_set_gpio_level(PRI_OUT_A, max_x - ((a.val - a.configs.pri_out_offset) >> bit_diff));
    pwm_set_gpio_level(PRI_OUT_B, max_x - ((b.val - b.configs.pri_out_offset) >> bit_diff));
    pwm_set_gpio_level(SEC_OUT_A, max_x - ((mod_a.val - a.configs.sec_out_offset) >> bit_diff));
    pwm_set_gpio_level(SEC_OUT_B, max_x - ((mod_b.val - b.configs.sec_out_offset) >> bit_diff));

    gpio_put(TRIG_OUT_A, !a.end_of_cycle);
    gpio_put(TRIG_OUT_B, !b.end_of_cycle);
    return true;
}

void write_other_leds() {
    uint8_t a_brightness = (a.val < half_y)? 0 : a.val - half_y >> 7;
    uint8_t a_mod_brightness = (mod_a.val < half_y)? 0 : mod_a.val - half_y >> 7;

    uint8_t b_brightness = (b.val < half_y)? 0 : b.val - half_y >> 7;
    uint8_t b_mod_brightness = (mod_b.val < half_y)? 0 : mod_b.val - half_y >> 7;

    // write signal indicators
    leds.setPixelColor(PRI_A_LED, (!a.running)? 0 : a_brightness_table[a_brightness]);
    leds.setPixelColor(SEC_A_LED, (!a.running && !mod_a.running)? 0 : a_brightness_table[a_mod_brightness]);
    leds.setPixelColor(PRI_B_LED, (!b.running)? 0 : b_brightness_table[b_brightness]);
    leds.setPixelColor(SEC_B_LED, (!b.running && !mod_b.running)? 0 : b_brightness_table[b_mod_brightness]);

    // write trig LEDs
    leds.setPixelColor(TRIG_A_LED, (a.eos_led)? a_colour : black);
    leds.setPixelColor(TRIG_B_LED, (b.eos_led)? b_colour : black);

    // write follow LED
    leds.setPixelColor(FLW_LED, (b.follow_mode != DISABLED)? mix_colour : black);
}

// responsible for triggering saving code
void encoder_long_press_ISR() {
    save_mod_pos_flag = true;
    pwm_set_enabled(a_pwm_slice, false);
    pwm_set_enabled(b_pwm_slice, false);
}

// called when the follow button is pressed
void follow_ISR() {
    b.toggle_follow_mode();
}

// called when rising input trigger detected on A sync
void a_sync_ISR() {
    a.reset();
    a.running = true;
    if (b.follow_mode != DISABLED) b_sync_ISR();
}

// called when rising input trigger detected on B sync
void b_sync_ISR() {
    b.reset();
    b.running = true;
}

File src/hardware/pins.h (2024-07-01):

// pin assignments for the SAM D21
// use these names to refer to them
#ifndef PINS_H
#define PINS_H


#define LIN_TIME_A 27
#define SIG_IN_A 17
#define MUX_A 26
#define PRI_OUT_A 13  // don't know what PWM reg this corresponds to
#define SEC_OUT_A 12  // same as above
#define TRIG_OUT_A 8

#define LIN_TIME_B 28
#define SIG_IN_B 18
#define MUX_B 29
#define PRI_OUT_B 1  // don't know what PWM reg this corresponds to
#define SEC_OUT_B 0  // same as above
#define TRIG_OUT_B 5

#define LED_PIN 25
#define LED_DATA {LED_PIN, -1, -1, -1, -1, -1, -1, -1}

#define ALGO_ENC_1 23
#define ALGO_ENC_2 22
#define ALGO_BTN 24
#define FLW_BTN 7

#define MUX_S0 19
#define MUX_S1 20
#define MUX_S2 21

// led assignments
#define NUM_LEDS 23
#define NUM_RING_LEDS 16
#define FLW_LED 16
#define TRIG_B_LED 17
#define PRI_B_LED 18
#define SEC_B_LED 19
#define SEC_A_LED 20
#define PRI_A_LED 21
#define TRIG_A_LED 22

// mux A assignments
#define R_CV_A   3
#define R_POT_A  0
#define S_CV_A   2
#define S_POT_A  1
#define M_CV_A   4
#define SW_1_A   5
#define SW_2_A   6
#define EXP_CV_A 7

// mux B assignments
#define R_CV_B   1
#define R_POT_B  2
#define S_CV_B   0
#define S_POT_B  3
#define M_CV_B   4
#define SW_1_B   5
#define SW_2_B   6
#define EXP_CV_B 7

#endif

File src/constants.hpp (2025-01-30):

#include <stdint.h>

#ifndef CONSTANTS_HPP
#define CONSTANTS_HPP

#define BITS_X 11
#define BITS_Y 16
#define ACC_BITS 32
constexpr uint16_t max_x = (1 << BITS_X) - 1;
constexpr uint16_t max_y = (1 << BITS_Y) - 1;
constexpr uint64_t max_acc = (1ull << ACC_BITS) - 1;
constexpr uint16_t half_x = (1 << (BITS_X - 1)) - 1;
constexpr uint16_t half_y = (1 << (BITS_Y - 1)) - 1;
constexpr uint16_t bit_diff = BITS_Y - BITS_X;  // 5
constexpr uint16_t acc_downshift = ACC_BITS - BITS_X;

#define BITS_ADC 12
constexpr uint16_t max_adc = (1 << BITS_ADC) - 1;
constexpr uint16_t half_adc = (1 << (BITS_ADC - 1)) - 1;

#define PWM_FREQ_kHz 44.1
#define BIT_DEPTH 11
#define CLOCK_FREQ 125000000
#define LOOPS_PER_SEC 1018

#define FM_ATTENUATION 6

#define TRIG_LENGTH_MS 3
#define TRIG_LED_LENGTH_MS 75

// modulation algorithm settings
#define CRUSH_MIN 13
#define CRUSH_MAX 16
#define FM_ALGO_AMT 8
#define SRR_AMT 7
constexpr uint16_t trig_threshold = half_y / 2 * 3;

#endif

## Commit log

2024-05-15 minimal arduino program
2024-06-16 encoder working
2024-07-01 switched to running on a single core. oscillator stability improved
    [spelltwister.ino]
2024-07-01 fixed envelope output scaling
    [spelltwister.ino, waveformer.cpp]
2024-07-01 Revert "switched to running on a single core. oscillator stability improved"
    This reverts commit 2e722367fc0fcd412f9b5448aee62c4c5cb1a08d.
    [spelltwister.ino]
2024-07-05 smoothing on pitch input
2024-07-11 fixed bugs in nvm wrapper
    [nvm_wrapper.cpp]
2024-07-11 started work on calibration routine (untested)
2024-07-12 added startup led pattern
2024-07-12 first draft of calibration routine done
2024-07-16 added print all option to waveformer, refactoring
2024-07-17 refactor of config and calibration
2024-07-25 modified waveformer output printing
2024-07-25 bug fixing (lots of integer overflow)
    [waveformer.cpp]
2024-07-25 changed waveformer method names to reflect function, modified calibration calculations
2024-07-30 solved instability in modulator index cv
    [spelltwister.ino, waveformer.cpp]
2024-08-06 fixed bug where device wouldn't boot unless connected to usb
    [spelltwister.ino]
2024-08-06 switched tabs for spaces in generated tables
2024-08-09 calibration led sequences working
2024-08-09 calibration routine working!
2024-08-12 set up nvm storing of calibration data, fixed brightness inversion
    [calibration.cpp, generate_colours.py, nvm_wrapper.cpp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]
2024-08-15 modified calibration routine, working!
2024-08-15 calibration procedure has higher accuracy now
2024-08-16 better accuracy on pitch
2024-08-16 changed calibration to be 1 and 3v again
2024-08-16 slight bug fix with saving
    [nvm_wrapper.cpp]
2024-08-18 added custom adc filter, changed defines
2024-08-19 adc filter working! could be improved
2024-08-21 crazy wacky sound
    glitches when you play an ascending interval on the keyboard, will resume it's previous pitch after a couple seconds.
    [adc_filter.cpp]
2024-08-22 filter tuned!
2024-08-22 cleaning, put margins in ADC filter constructor
2024-08-23 multiple ADC filter modes
2024-08-27 DDS_Wrapper created, bug fix in reset
    [waveformer.cpp]
2024-08-28 switch arduino.h for stdint.h wherever possible
2024-09-04 filter properly tuned, updates to serial plotter
2024-09-04 added schem and pcb to git
    [LEDs.kicad_sch, dsug_cctv_BOARD.kicad_pcb, dsug_cctv_BOARD.kicad_sch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]
2024-09-05 redid power circuitry
    5V is now switching regulator, separate LDO for analog and digital
    [dsug_cctv_BOARD.kicad_sch, module.kicad_sch]
2024-09-05 upgraded led level shifter
    [dsug_cctv_BOARD.kicad_sch]
2024-09-05 minor changes
    switched caps on V/O input, changed resistors for trig in
    [module.kicad_sch]
2024-09-10 fixing schematic issues, change output caps
    [dsug_cctv_BOARD.kicad_sch, module.kicad_sch]
2024-09-17 pcb rev2.5
    [dsug_cctv_BOARD.kicad_pcb, dsug_cctv_BOARD.kicad_sch, module.kicad_sch]
2024-09-17 swapped 10uF for 22uF caps
    [dsug_cctv_BOARD.kicad_sch]
2024-10-03 minor pcb changes
    [dsug_cctv_BOARD.kicad_pcb, dsug_cctv_BOARD.kicad_sch, module.kicad_sch]
2024-10-03 somewhat working adc filter
2024-10-30 correct pitch calibration numbers
    [calibration.cpp]
2024-10-30 values for v/o filter and algorithms tuned
2024-10-31 voltage range changed from 8 to 7 octaves, code refactored to fit
2024-10-31 filter tuning
2024-11-03 loads from calibration
2024-11-10 fix to manual commit mode
    [spelltwister.ino]
2024-11-12 switched pin that inductor on buck recitifier is connected to
    [dsug_cctv_BOARD.kicad_sch]
2024-11-12 added four more decoupling caps
    [dsug_cctv_BOARD.kicad_sch]
2024-11-12 library name updating, footprint swaps
    [LEDs.kicad_sch, dsug_cctv_BOARD.kicad_sch, module.kicad_sch]
2024-11-13 beginning of pcb changes
    [dsug_cctv_BOARD.kicad_pcb]
2024-11-13 fixed some calibration info
    [calibration.cpp, waveformer.cpp]
2024-11-15 encoder direction calibration step added
2024-11-16 encoder direction updates immediately from calibration
2024-11-17 vco follow range fixed
    [waveformer.cpp]
2024-11-17 multiple follow options
    not a great implementation, lfo's don't sync together currently
2024-11-19 fixed encoder glitch and removed RAR for algo input
    [waveformer.cpp]
2024-11-22 ghost LEDs functioning
2024-11-22 slight fix to envelope operation
    [waveformer.cpp]
2024-12-04 oversampling pitch input
    hopefully this finally solves the pitch stability issue
    [adc_filter.cpp, waveformer.cpp]
2024-12-19 slightly lowered oscillator pitch, implemented phase dithering
    [generate_phasors.py, waveformer.cpp]
2024-12-19 lowered lfo pitch, fixed phase dithering
    [generate_phasors.py]
2025-01-09 fixes
    incorrect calibration no longer wraps around
    trig length increased
    [constants.hpp, waveformer.cpp]
2025-01-10 minor hardware changes
    [dsug_cctv_BOARD.kicad_pcb, dsug_cctv_BOARD.kicad_sch]
2025-01-10 changed indicator LED behaviour
2025-01-18 pcb changes
    [dsug_cctv_BOARD.kicad_pcb]
2025-01-23 fixed CV inversion for shape and ratio
    [waveformer.cpp]
2025-01-23 update LEDs less often for higher UI freq
2025-01-25 more smoothing on pitch
2025-01-25 inverted S&H and rungle behaviour
    [constants.hpp]
2025-01-26 slight time knob bug fix
    [waveformer.cpp]
2025-01-26 switch UF2
2025-01-30 finally fixed phasor wrap bug
    [waveformer.cpp]
2025-01-30 slow phasors code (buggy)
    [generate_phasors.py]
2025-01-30 new uf2 and fixed clip function
    [waveformer.cpp]
2025-02-01 attempt at envelope bug fix
    [waveformer.cpp]
2025-02-04 calibration now takes more values
2025-02-05 removed STEP enum from calibration
2025-02-05 slight calibration refactor
2025-02-06 multipoint calibration!
2025-02-07 shift calibration down further
2025-02-09 fixed time cv inversion
    [waveformer.cpp]
2025-02-09 implemented adc linearization table
2025-02-13 modulated envelope behaviour fixed
    [spelltwister.ino]
2025-02-13 fixed slope behaviour, all bipolar outputs (temporary)
    [waveformer.cpp]
2025-02-27 unmodulated outputs now go between -5 and 5V
2025-02-27 output offset calibration working pretty well!
